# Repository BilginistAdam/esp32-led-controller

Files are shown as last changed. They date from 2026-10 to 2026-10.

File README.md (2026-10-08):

<p align="center">
  <picture>
    <source media="(prefers-color-scheme: dark)" srcset="docs/logo/banner-dark.svg">
    LED Controller · Bilginier
  </picture>
</p>

# LED Controller — ESP32-C3 LED Şerit Kontrolcüsü

12–24 V LED şeritleri WiFi üzerinden açıp kapatan ve PWM ile dimleyen küçük bir kontrol kartı. Proje KiCad donanım dosyalarını, iki firmware seçeneğini (ESPHome / PlatformIO) ve 3D yazıcıyla basılabilen bir kutuyu içerir.

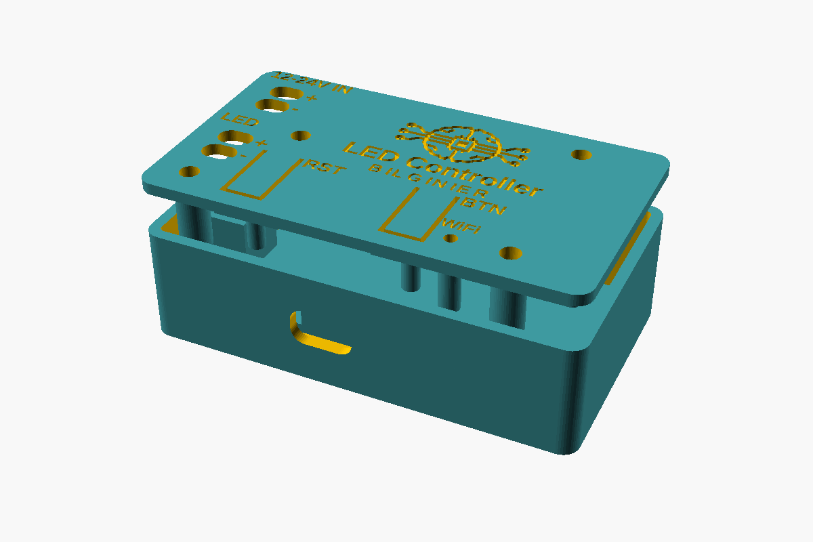
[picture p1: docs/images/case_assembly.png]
Kutu


| PCB üst | Şematik |
|---|---|
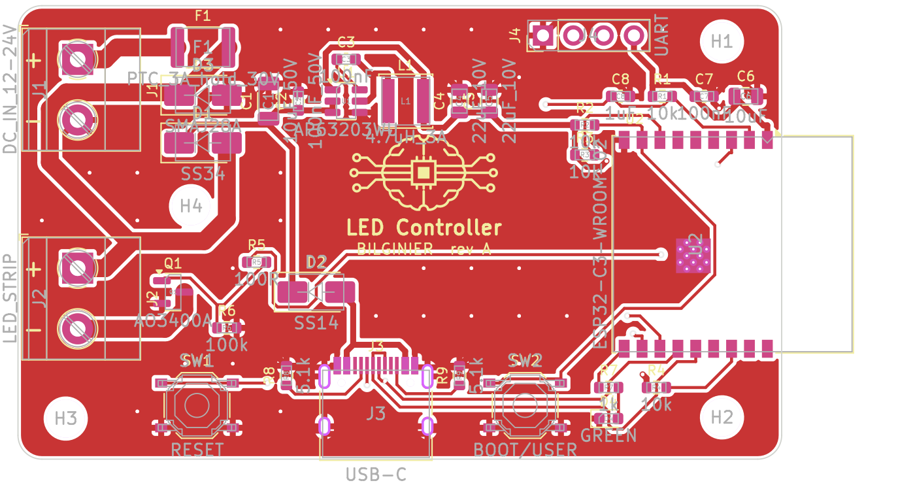
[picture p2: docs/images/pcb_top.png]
PCB
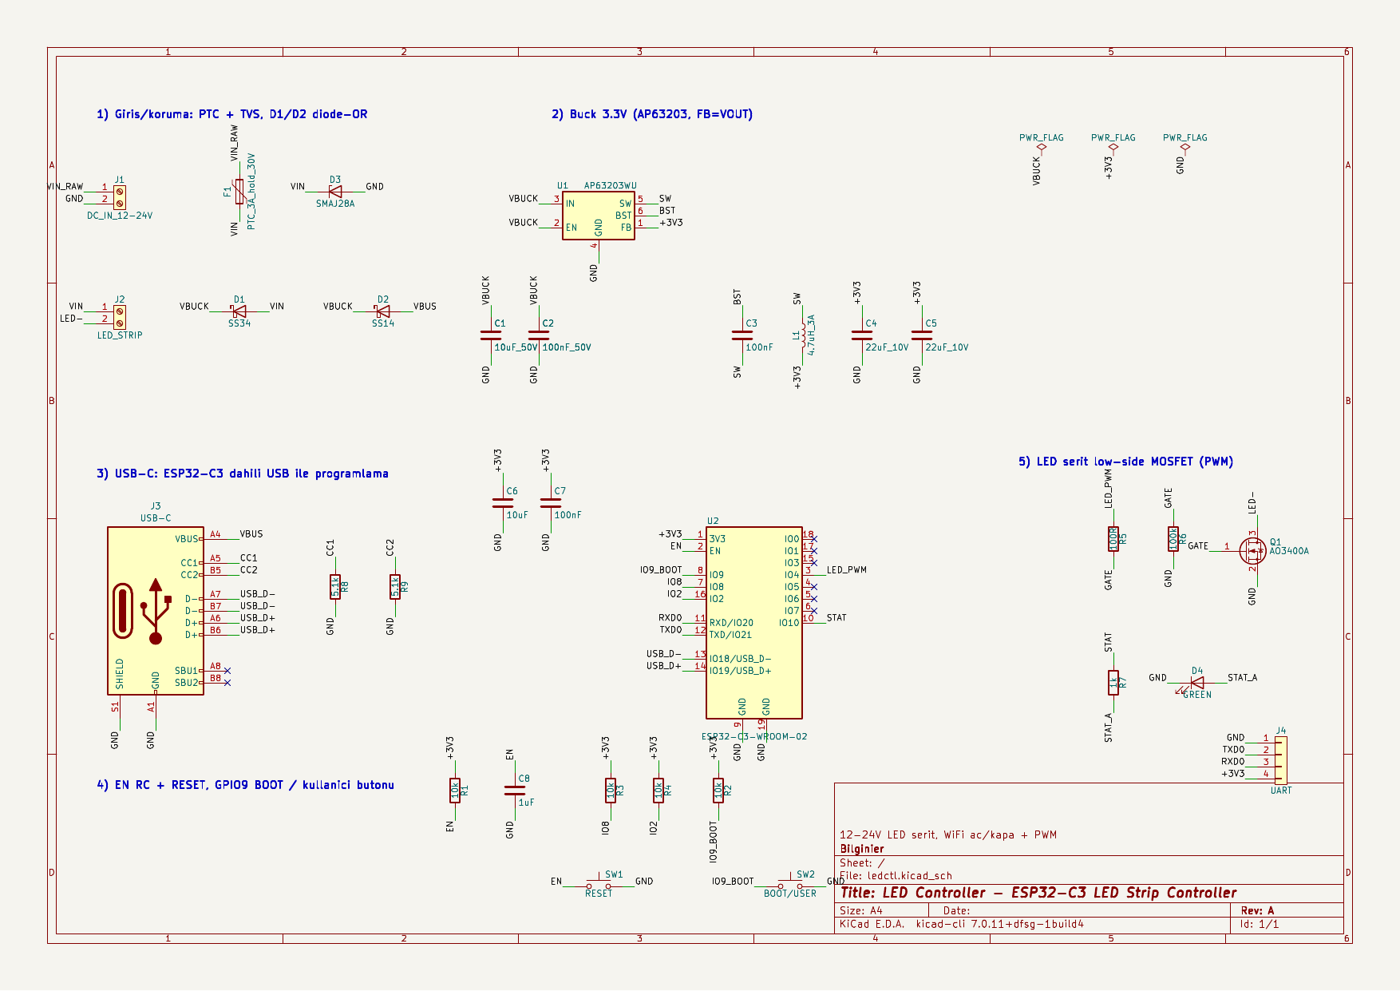
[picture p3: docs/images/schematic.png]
Şematik
|  |  |

## Özellikler

- **Kontrol:** ESP32-C3-WROOM-02 (WiFi + BLE). Programlama dahili USB üzerinden USB-C ile yapılıyor, ayrı bir USB-UART çipi yok.
- **Giriş:** 12–24 V DC. PTC sigorta ve TVS ile korunuyor. AP63203 buck regülatör 3.3 V üretiyor.
- **Besleme:** D1/D2 diyotlarıyla kart adaptörden **ya da** sadece USB'den beslenebiliyor, yani programlarken adaptör gerekmiyor.
- **LED sürme:** LED şeridini low-side AO3400A MOSFET anahtarlıyor. 20 kHz PWM kullanılıyor, böylece duyulabilir vızıltı olmuyor. Gate'teki pull-down sayesinde LED boot sırasında kapalı kalıyor.
- **Arayüz:** RESET butonu, BOOT/kullanıcı butonu ve durum LED'i var.
- **Kart:** 64 × 38 mm, 2 katman, 4 × M3 montaj deliği.

## Klasör yapısı

```
hardware/          KiCad projesi (şematik, PCB, proje sembol kütüphanesi)
  BOM.md / BOM.csv malzeme listesi (okunabilir tablo / üretici formatı)
  ledctl-gerbers.zip   üreticiye (JLCPCB/PCBWay vb.) doğrudan yüklenebilir
  fabrication/     Gerber, drill, pick-and-place (pos) dosyaları
  scripts/         şematik/PCB'yi üreten Python betikleri (design.py = tek kaynak)
firmware/
  esphome/         Home Assistant için ESPHome konfigürasyonu
  platformio/      bağımsız Arduino firmware'i (web arayüzü + REST API)
    prebuilt/      derlenmiş factory imajı (0x0 adresine yazılır)
enclosure/         OpenSCAD kaynak + basılmaya hazır STL'ler
docs/              şematik PDF, PCB montaj PDF'i, görseller
  logo/            Bilginier logosu (SVG) + üretici betik (PCB, kutu ve banner aynı kaynaktan)
```

## Malzeme listesi (BOM)

Ayrıntılı liste için [`hardware/BOM.md`](hardware/BOM.md), makineli montaj için [`hardware/BOM.csv`](hardware/BOM.csv) dosyasına bak.

| Adet | Ref | Parça | LCSC |
|---:|---|---|---|
| 1 | U2 | ESP32-C3-WROOM-02-N4 | C2934560 |
| 1 | U1 | AP63203WU-7 (3.3 V buck) | C780769 |
| 1 | Q1 | AO3400A | C20917 |
| 1 | L1 | FNR4030S4R7MT, 4.7 µH | C167874 |
| 1 / 1 / 1 | D1 / D2 / D3 | SS34 / SS14 / SMAJ28A | C8678 / C2480 / C353458 |
| 1 | D4 | Yeşil LED 0603 | C72043 |
| 1 | F1 | PTC 1812 (bkz. BOM.md notu) | — |
| 1 | C1 | 10 µF 50 V 1206 | C13585 |
| 3 | C2, C3, C7 | 100 nF 50 V 0603 | C14663 |
| 2 | C4, C5 | 22 µF 25 V 0805 | C45783 |
| 1 / 1 | C6 / C8 | 10 µF 0805 / 1 µF 0603 | C15850 / C15849 |
| 4 | R1–R4 | 10 kΩ 0603 | C25804 |
| 1 / 1 / 1 | R5 / R6 / R7 | 100 Ω / 100 kΩ / 1 kΩ 0603 | C22775 / C25803 / C21190 |
| 2 | R8, R9 | 5.1 kΩ 0603 | C23186 |
| 2 | J1, J2 | Phoenix 1715721, 2P 5.08 mm | C480516 |
| 1 | J3 | USB-C HRO TYPE-C-31-M-12 | C165948 |
| 1 | J4 | 1×4 pin header (opsiyonel) | C2337 |
| 2 | SW1, SW2 | TS-1187A-B-A-B | C318884 |
| 4 | — | M3 × 20 vida (kutu) | — |

JLCPCB montaj için hazır dosyalar: `hardware/fabrication/ledctl-bom-jlcpcb.csv` ve `ledctl-cpl-jlcpcb.csv`.

## Pin haritası

| GPIO | İşlev |
|---|---|
| IO4 | LED PWM → R5 → Q1 gate |
| IO9 | BOOT / kullanıcı butonu (aktif düşük) |
| IO10 | Durum LED'i (aktif yüksek) |
| IO18 / IO19 | USB D− / D+ (USB-C) |
| IO20 / IO21 | UART RX / TX (J4, opsiyonel) |

## Firmware

### Seçenek A: ESPHome (Home Assistant)

```bash
cd firmware/esphome
cp secrets.yaml.example secrets.yaml   # WiFi bilgilerini gir
esphome run ledctl.yaml                # ilk yükleme USB-C üzerinden
```

Bu seçenek Home Assistant'a "LED Serit" adlı, dimlenebilir bir ışık olarak eklenir. Butona basınca LED açılıp kapanır, durum LED'i WiFi bağlantısını gösterir.

### Seçenek B: PlatformIO (bağımsız)

```bash
cd firmware/platformio
pio run -t upload        # USB-C
pio device monitor
```

1. **WiFi kurulumu:** İlk açılışta kart `LedCtrl-Setup` adında bir WiFi ağı açar. Bu ağa bağlanıp açılan sayfadan kendi WiFi bilgilerini gir.
2. **Web arayüzü:** Kurulumdan sonra `http://led-ctrl.local` adresinden aç/kapat ve parlaklık ayarı yapılabilir.
3. **REST API:**
   ```bash
   curl http://led-ctrl.local/api/state
   curl -X POST http://led-ctrl.local/api/state -d '{"on":true,"brightness":60}'
   curl -X POST http://led-ctrl.local/api/toggle
   ```
4. **Buton:**
   - Kısa basış: aç/kapat
   - Basılı tutma: parlaklığı 100 → 75 → 50 → 25 → 10 sırasıyla değiştirir
   - 8 saniye basılı tutma: WiFi ayarlarını siler
5. **Durum LED'i:**
   - Sürekli yanık: bağlı
   - Yavaş yanıp sönme: bağlanıyor
   - Hızlı yanıp sönme: kurulum modunda
6. **Diğer:** Son durum NVS'e kaydedilir, elektrik kesilip gelince geri yüklenir. Ayrıca OTA güncelleme (ArduinoOTA) destekleniyor.

Hazır imajı yazmak için:

```bash
esptool.py --chip esp32c3 write_flash 0x0 firmware/platformio/prebuilt/ledctl-factory.bin
```

> **Yükleme başlamazsa:** **BOOT**'a basılı tutarken **RESET**'e bas ve bırak. Kart indirme moduna geçer. Normalde USB üzerinden otomatik reset yeterli olur.

## Kutu (3D baskı)

| Parça | Dosya | Baskı yönü |
|---|---|---|
| Gövde | `enclosure/ledctl_case_base.stl` | taban aşağıda |
| Kapak | `enclosure/ledctl_case_lid.stl` | yüzü aşağıda (dosya zaten bu yönde) |

- **Önerilen baskı ayarları:** PETG veya PLA, 0.2 mm katman, %20–30 doluluk. Destek gerekmiyor.
- **Montaj:** 4 adet **M3 × 20** vida kapaktan girer, PCB'yi sıkıştırır ve gövdedeki direklere tutunur. Vidalar plastiğe kendi yolunu açabilir; isteğe bağlı olarak `pilot_d = 4.0` ile heat-set insert de kullanılabilir.
- **Duvara montaj:** Tabanda 20 mm aralıklı iki anahtar deliği var, en fazla 8 mm başlı vida uygun. USB-C aşağı bakacak şekilde asılır.
- **Bantla montaj:** Taban tamamen düz olduğu için çift taraflı bantla da yapıştırılabilir.
- **Butonlar:** RESET ve BOOT butonları kapaktaki esnek dillerle basılır. Durum LED'inin ışığı kapaktaki tüpten görünür.
- **Terminaller:** Vidalarına kapaktaki deliklerden tornavidayla erişilir.
- **Ölçüler:** `enclosure/ledctl_case.scad` içindeki parametrelerden (tolerans, duvar kalınlığı, yükseklik) değiştirilebilir.

```bash
openscad -D 'part="base"' -o enclosure/ledctl_case_base.stl enclosure/ledctl_case.scad
openscad -D 'part="lid"'  -o enclosure/ledctl_case_lid.stl  enclosure/ledctl_case.scad
```

## Üretim

1. `hardware/ledctl-gerbers.zip` dosyasını PCB üreticisine yükle. Ayarlar: 2 katman, 1.6 mm, 1 oz bakır.
2. Montaj için `hardware/BOM.csv` (okunabilir hali: `hardware/BOM.md`) ve `hardware/fabrication/ledctl-pos.csv` dosyalarını kullan.
3. ESP modülünün anteni kartın sağ kenarından yaklaşık 6 mm dışarı taşar. Bu bilinçli bir tercih: antenin altında bakır olmaması gerekiyor. Kutu bu taşmaya göre tasarlandı.

## Tasarım notları ve sınırlar

- **Akım:** AO3400A ile kart yaklaşık **3 A** LED akımı için uygun. 24 V'ta bu yaklaşık 70 W, 12 V'ta yaklaşık 36 W eder. Daha yüksek akım için daha güçlü bir MOSFET kullanılmalı ve LED izleri genişletilmeli.
- **Gerilim:** AP63203 en fazla 32 V girişe dayanır. 24 V adaptörlerde sorun yok. TVS (SMAJ28A) kısa süreli darbelere karşı korur, ama sürekli aşırı gerilimden korumaz.
- **F1 sigorta:** 3 A / 24 V için 1812 kılıfta uygun bir PTC yok. Seçenekler [`hardware/BOM.md`](hardware/BOM.md) notunda anlatılıyor.
- **Routing:** İzler Freerouting ile otomatik çizildi. DRC'de elektriksel hata yok, sadece kozmetik silkscreen uyarıları var. Sipariş vermeden önce KiCad 8/9'da ERC ve DRC'yi kendin de çalıştır.
- **Yeniden üretme:** `hardware/scripts/` içindeki betikler şematik ve PCB'yi `design.py` ve `placement.py` dosyalarından üretir. Logo ve isim en son `add_branding.py` ile silkscreen'e eklenir. Bunun için KiCad 7+ Python (`pcbnew`) ve otomatik routing için Freerouting gerekir (`FREEROUTING_JAR` ortam değişkeni).

## Lisans

[MIT](LICENSE). Donanım dosyaları, firmware ve kutu dahil projenin tamamı bu lisansla yayınlanır.

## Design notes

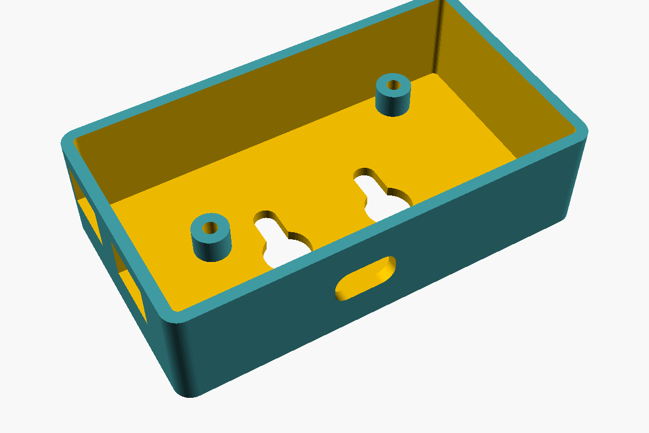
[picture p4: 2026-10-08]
docs/images/case_base.png

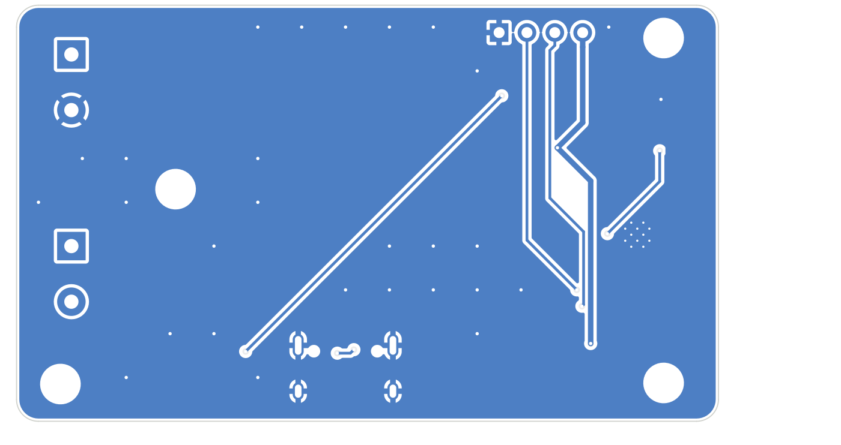
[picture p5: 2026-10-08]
docs/images/pcb_bottom.png

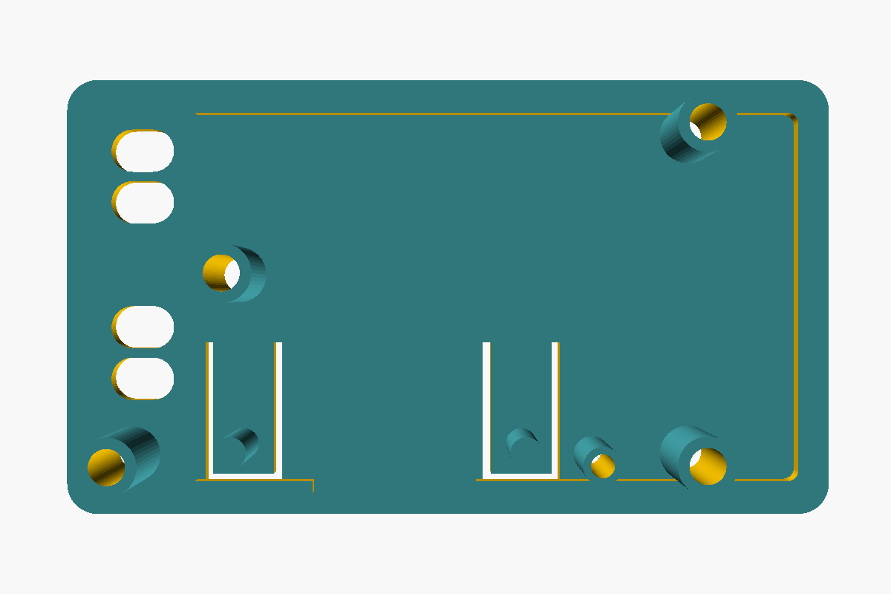
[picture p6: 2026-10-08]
docs/images/case_lid.png

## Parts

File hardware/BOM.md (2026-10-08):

<p align="center">Bilginier</p>

# Malzeme Listesi (BOM) — LED Controller rev A

Bir kart için 23 kalem ve toplam 32 parça gerekiyor. LCSC numaralarının hepsi Ekim 2026'da lcsc.com'da doğrulandı. Stok durumu sürekli değiştiği için sipariş öncesi yeniden kontrol et.

**Hangi dosyayı kullanmalısın:**

- **Elle sipariş:** `BOM.csv` (üretici parça numarası ve LCSC numarası birlikte).
- **JLCPCB montaj:** `fabrication/ledctl-bom-jlcpcb.csv` ve `fabrication/ledctl-cpl-jlcpcb.csv`. J4 bu listelerde yok, istersen elle lehimlenir.

## Aktif parçalar

| Adet | Ref | Değer | Açıklama | Kılıf | Üretici parça no | LCSC |
|---:|---|---|---|---|---|---|
| 1 | U2 | ESP32-C3-WROOM-02-N4 | WiFi/BLE modül, 4 MB flash, PCB anten | Modül | Espressif ESP32-C3-WROOM-02-N4 | [C2934560](https://www.lcsc.com/product-detail/C2934560.html) |
| 1 | U1 | AP63203WU | Senkron buck, 3.8–32 V → 3.3 V / 2 A | TSOT-23-6 | Diodes AP63203WU-7 | [C780769](https://www.lcsc.com/product-detail/C780769.html) |
| 1 | Q1 | AO3400A | N-MOSFET 30 V / 5.7 A, lojik seviye | SOT-23 | AOS AO3400A | [C20917](https://www.lcsc.com/product-detail/C20917.html) |
| 1 | D1 | SS34 | Schottky 40 V / 3 A (adaptör → buck) | SMA | MDD SS34 | [C8678](https://www.lcsc.com/product-detail/C8678.html) |
| 1 | D2 | SS14 | Schottky 40 V / 1 A (USB → buck) | SMA | MDD SS14 | [C2480](https://www.lcsc.com/product-detail/C2480.html) |
| 1 | D3 | SMAJ28A | TVS 28 V, tek yönlü | SMA | Jingdao SMAJ28A | [C353458](https://www.lcsc.com/product-detail/C353458.html) |
| 1 | D4 | Yeşil LED | Durum LED'i | 0603 | Everlight 19-217/GHC-YR1S2/3T | [C72043](https://www.lcsc.com/product-detail/C72043.html) ¹ |

## Pasifler

| Adet | Ref | Değer | Açıklama | Kılıf | Üretici parça no | LCSC |
|---:|---|---|---|---|---|---|
| 1 | L1 | 4.7 µH | Güç bobini, Isat 3.2 A, ekranlı | 4×4 mm | Changjiang FNR4030S4R7MT | [C167874](https://www.lcsc.com/product-detail/C167874.html) |
| 1 | F1 | PTC | Resetlenebilir sigorta | 1812 | **belirlenecek** ² | — |
| 1 | C1 | 10 µF 50 V | Buck giriş, X5R | 1206 | Samsung CL31A106KBHNNNE | [C13585](https://www.lcsc.com/product-detail/C13585.html) |
| 3 | C2, C3, C7 | 100 nF 50 V | Buck HF (C2), bootstrap (C3), modül (C7), X7R | 0603 | Yageo CC0603KRX7R9BB104 | [C14663](https://www.lcsc.com/product-detail/C14663.html) |
| 2 | C4, C5 | 22 µF 25 V | Buck çıkış, X5R | 0805 | Samsung CL21A226MAQNNNE | [C45783](https://www.lcsc.com/product-detail/C45783.html) |
| 1 | C6 | 10 µF 25 V | Modül besleme, X5R | 0805 | Samsung CL21A106KAYNNNE | [C15850](https://www.lcsc.com/product-detail/C15850.html) |
| 1 | C8 | 1 µF 50 V | EN RC gecikmesi, X5R | 0603 | Samsung CL10A105KB8NNNC | [C15849](https://www.lcsc.com/product-detail/C15849.html) ¹ |
| 4 | R1–R4 | 10 kΩ %1 | EN ve strapping pull-up'ları | 0603 | UNI-ROYAL 0603WAF1002T5E | [C25804](https://www.lcsc.com/product-detail/C25804.html) ¹ |
| 1 | R5 | 100 Ω %1 | Gate seri direnci | 0603 | UNI-ROYAL 0603WAF1000T5E | [C22775](https://www.lcsc.com/product-detail/C22775.html) |
| 1 | R6 | 100 kΩ %1 | Gate pull-down | 0603 | UNI-ROYAL 0603WAF1003T5E | [C25803](https://www.lcsc.com/product-detail/C25803.html) |
| 1 | R7 | 1 kΩ %1 | Durum LED'i direnci | 0603 | UNI-ROYAL 0603WAF1001T5E | [C21190](https://www.lcsc.com/product-detail/C21190.html) |
| 2 | R8, R9 | 5.1 kΩ %1 | USB-C CC pull-down | 0603 | UNI-ROYAL 0603WAF5101T5E | [C23186](https://www.lcsc.com/product-detail/C23186.html) |

## Elektromekanik

| Adet | Ref | Değer | Açıklama | Üretici parça no | LCSC |
|---:|---|---|---|---|---|
| 2 | J1, J2 | 2P, 5.08 mm | Vidalı klemens (J1 = 12–24 V giriş, J2 = LED şerit) | Phoenix Contact 1715721 | [C480516](https://www.lcsc.com/product-detail/C480516.html) |
| 1 | J3 | USB-C 16P | USB 2.0 Type-C dişi | HRO TYPE-C-31-M-12 | [C165948](https://www.lcsc.com/product-detail/C165948.html) |
| 1 | J4 | 1×4, 2.54 mm | UART header (opsiyonel, 1×40 şeritten kesilir) | BOOMELE 2.54-1*40P | [C2337](https://www.lcsc.com/product-detail/C2337.html) |
| 2 | SW1, SW2 | 5.1×5.1×1.5 mm | Tact switch (RESET / BOOT) | XKB TS-1187A-B-A-B | [C318884](https://www.lcsc.com/product-detail/C318884.html) |

## Kutu ve montaj

| Adet | Parça | Not |
|---:|---|---|
| 1 | Gövde (`enclosure/ledctl_case_base.stl`) | PETG veya PLA |
| 1 | Kapak (`enclosure/ledctl_case_lid.stl`) | Yüzü aşağı basılır, logo kazınmış |
| 4 | M3 × 20 vida | Plastiğe yol açan tip, ya da M3 heat-set insert ile makine vidası |
| 2 | Duvar vidası + dübel | Başı en fazla 8 mm, gövdesi en fazla 4 mm (anahtar deliği için) |
| — | Çift taraflı bant | Opsiyonel, düz taban için |

## PCB

| Özellik | Değer |
|---|---|
| Ölçü | 64 × 38 mm |
| Katman | 2 |
| Kalınlık | 1.6 mm |
| Bakır | 1 oz |
| Min. iz / boşluk | 0.2 / 0.2 mm |
| Min. delik | 0.3 mm (via) |
| Üretim dosyası | `ledctl-gerbers.zip` |

## Notlar

¹ **Stok:** Bu parçalar kontrol sırasında LCSC mağazasında stokta yoktu ya da azdı. Hepsi yaygın parçalar, JLCPCB montaj stoğu ayrı tutulur. Yoksa aynı değer ve kılıfta başka bir parça kullanılabilir.

² **F1 (PTC sigorta):** 1812 kılıfta 24 V'a dayanıp 3 A taşıyan bir PTC bulunmuyor. 24 V sınıfı 1812 PTC'ler en fazla 1.5 A civarında kalıyor, 3 A olanlar ise 8 V'a kadar dayanıyor (örneğin C21004). Bu yüzden kalem şimdilik boş bırakıldı. Seçenekler:

- **Daha düşük akım:** 1.5 A / 24 V'luk bir 1812 PTC kullan. Şerit akımı da bununla sınırlı kalır.
- **Daha büyük kılıf:** 2920 kılıfta daha yüksek akımlı bir PTC kullan. Bunun için PCB'de footprint değişikliği gerekir.
- **Tek kullanımlık sigorta:** SMD bir eriyen sigorta kullan. Bu da PCB değişikliği gerektirir.

Prototip için F1 yerine 0 Ω köprü ya da kısa bir tel de konabilir, ama bu durumda aşırı akım koruması kalmaz.

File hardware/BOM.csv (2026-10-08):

Qty | References | Value | Description | Package / Footprint | Manufacturer part number | LCSC
1 | U2 | ESP32-C3-WROOM-02-N4 | Wi-Fi/BLE module, 4 MB flash, PCB antenna | ESP32-C3-WROOM-02 | Espressif ESP32-C3-WROOM-02-N4 | C2934560
1 | U1 | AP63203WU | Synchronous buck 3.8-32 V in, 3.3 V / 2 A out, 1.1 MHz | TSOT-23-6 | Diodes Inc. AP63203WU-7 | C780769
1 | Q1 | AO3400A | N-MOSFET 30 V / 5.7 A, logic level (LED strip switch) | SOT-23 | Alpha & Omega AO3400A | C20917
1 | L1 | 4.7uH | Power inductor 4.7 uH, Isat 3.2 A, shielded | 4.0 x 4.0 mm (FNR4030S) | Changjiang FNR4030S4R7MT | C167874
1 | D1 | SS34 | Schottky 40 V / 3 A (adapter -> buck, diode-OR) | SMA | MDD SS34 | C8678
1 | D2 | SS14 | Schottky 40 V / 1 A (USB VBUS -> buck, diode-OR) | SMA | MDD SS14 | C2480
1 | D3 | SMAJ28A | TVS 28 V standoff, unidirectional | SMA | Jingdao SMAJ28A | C353458
1 | D4 | GREEN | Status LED, green | 0603 | Everlight 19-217/GHC-YR1S2/3T | C72043
1 | F1 | PTC | Resettable fuse - see BOM.md note: no 1812 part covers 3 A at 24 V | 1812 | TBD
1 | C1 | 10uF 50V | Buck input bulk, X5R | 1206 | Samsung CL31A106KBHNNNE | C13585
3 | C2 C3 C7 | 100nF 50V | Buck input HF (C2), bootstrap (C3), module decoupling (C7), X7R | 0603 | Yageo CC0603KRX7R9BB104 | C14663
2 | C4 C5 | 22uF 25V | Buck output, X5R | 0805 | Samsung CL21A226MAQNNNE | C45783
1 | C6 | 10uF 25V | Module bulk decoupling, X5R | 0805 | Samsung CL21A106KAYNNNE | C15850
1 | C8 | 1uF 50V | EN RC delay, X5R | 0603 | Samsung CL10A105KB8NNNC | C15849
4 | R1 R2 R3 R4 | 10k 1% | EN pull-up, strapping pull-ups (IO9 / IO8 / IO2) | 0603 | UNI-ROYAL 0603WAF1002T5E | C25804
1 | R5 | 100R 1% | MOSFET gate series resistor | 0603 | UNI-ROYAL 0603WAF1000T5E | C22775
1 | R6 | 100k 1% | MOSFET gate pull-down (LED off during boot) | 0603 | UNI-ROYAL 0603WAF1003T5E | C25803
1 | R7 | 1k 1% | Status LED series resistor | 0603 | UNI-ROYAL 0603WAF1001T5E | C21190
2 | R8 R9 | 5.1k 1% | USB-C CC1/CC2 pull-downs (sink role) | 0603 | UNI-ROYAL 0603WAF5101T5E | C23186
2 | SW1 SW2 | TS-1187A | Tactile switch 5.1 x 5.1 x 1.5 mm (RESET / BOOT-user) | SMD 4-pad | XKB TS-1187A-B-A-B | C318884
1 | J3 | USB-C 16P | USB 2.0 Type-C receptacle, SMD + THT shell | HRO TYPE-C-31-M-12 | Korean Hroparts TYPE-C-31-M-12 | C165948
2 | J1 J2 | 2-pos 5.08 mm | Screw terminal block (J1 = 12-24 V in, J2 = LED strip) | Phoenix MKDS 1.5/2-5.08 | Phoenix Contact 1715721 | C480516
1 | J4 | 1x4 2.54 mm | UART/debug header (optional; cut from 1x40 strip) | PinHeader_1x04_P2.54mm | BOOMELE 2.54-1*40P | C2337
 |  |  | Enclosure hardware
4 |  | M3 x 20 | Pan head self-tapping (or machine screw with M3 heat-set inserts)

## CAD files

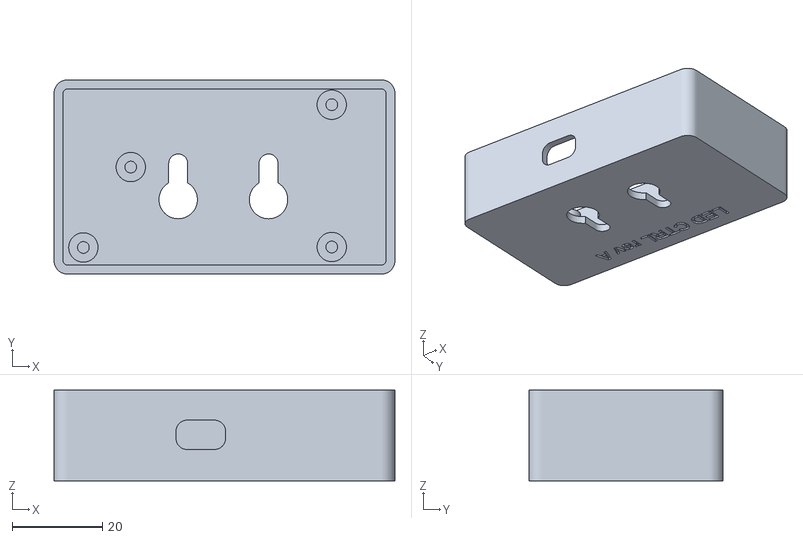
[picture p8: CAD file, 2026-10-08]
enclosure/ledctl_case_base.stl
75.5 x 43.0 x 20.1

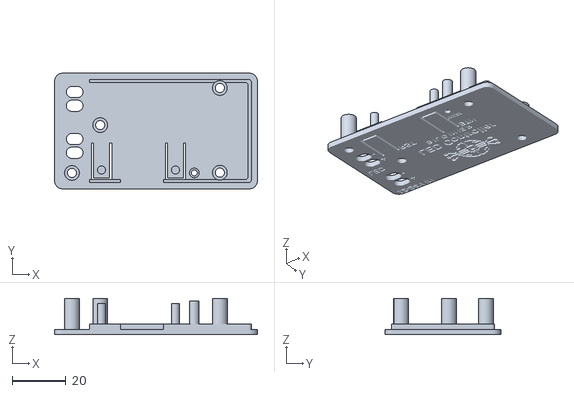
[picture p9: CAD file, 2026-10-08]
enclosure/ledctl_case_lid.stl
75.5 x 43.0 x 13.5

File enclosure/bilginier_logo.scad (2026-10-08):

// Generated by docs/logo/logo.py (stroke x1.8 for FDM engraving). Do not edit by hand.
// bilginier_logo(height): centered at origin, Y up.
module bilginier_logo(height = 12) {
  scale(height / 114.117)
  polygon(points = [[-91.13,27.17],[-92.27,28.31],[-93.62,29.21],[-95.11,29.83],[-96.69,30.14],[-98.31,30.14],[-99.89,29.83],[-101.38,29.21],[-102.73,28.31],[-103.87,27.17],[-104.77,25.83],[-105.39,24.34],[-105.70,22.75],[-105.70,21.14],[-105.39,19.55],[-104.77,18.06],[-103.87,16.72],[-102.08,15.09],[-100.65,14.33],[-98.31,13.74],[-96.69,13.74],[-94.35,14.33],[-92.92,15.09],[-91.13,16.72],[-89.93,18.70],[-83.34,18.70],[-72.29,7.65],[-71.53,7.09],[-70.00,6.70],[-62.24,6.70],[-62.85,5.32],[-63.37,3.18],[-93.93,3.18],[-94.65,4.52],[-95.67,5.77],[-97.62,7.21],[-99.11,7.83],[-100.69,8.14],[-103.11,8.02],[-104.65,7.56],[-106.73,6.31],[-108.35,4.52],[-109.39,2.34],[-109.74,-0.06],[-109.58,-1.66],[-109.11,-3.21],[-107.87,-5.28],[-106.73,-6.43],[-105.38,-7.32],[-103.89,-7.94],[-101.50,-8.30],[-99.11,-7.94],[-96.92,-6.91],[-95.13,-5.28],[-93.93,-3.30],[-63.32,-3.30],[-62.25,-6.82],[-70.00,-6.82],[-71.53,-7.20],[-72.29,-7.77],[-83.34,-18.82],[-89.93,-18.82],[-91.13,-16.83],[-92.27,-15.69],[-93.62,-14.79],[-95.89,-13.98],[-98.31,-13.86],[-99.89,-14.17],[-101.38,-14.79],[-102.73,-15.69],[-103.87,-16.83],[-104.77,-18.17],[-105.58,-20.45],[-105.70,-22.86],[-105.39,-24.45],[-104.35,-26.63],[-103.33,-27.88],[-102.08,-28.91],[-100.65,-29.67],[-98.31,-30.26],[-96.69,-30.26],[-94.35,-29.67],[-92.92,-28.91],[-91.13,-27.28],[-89.93,-25.30],[-82.00,-25.30],[-81.06,-25.16],[-79.71,-24.35],[-68.66,-13.30],[-60.82,-13.30],[-60.87,-15.17],[-60.40,-18.10],[-59.06,-21.70],[-55.97,-25.95],[-52.52,-28.34],[-52.19,-30.70],[-51.02,-33.82],[-49.25,-36.64],[-46.28,-39.63],[-41.56,-42.20],[-38.53,-42.80],[-37.82,-44.20],[-35.86,-46.83],[-33.69,-48.84],[-30.90,-50.58],[-27.83,-51.73],[-24.91,-52.23],[-21.63,-52.19],[-20.15,-51.90],[-18.19,-53.83],[-13.24,-56.37],[-9.93,-57.06],[-6.18,-57.05],[-5.27,-56.83],[-4.45,-56.35],[-3.65,-55.39],[-2.97,-52.85],[-2.26,-51.80],[-1.22,-51.10],[0.00,-50.86],[1.22,-51.10],[2.26,-51.80],[2.97,-52.85],[3.65,-55.39],[4.71,-56.54],[6.18,-57.05],[10.30,-57.04],[13.54,-56.29],[16.53,-54.93],[19.22,-53.00],[20.22,-51.92],[21.63,-52.19],[24.91,-52.23],[27.83,-51.73],[31.18,-50.42],[33.69,-48.84],[35.86,-46.83],[37.82,-44.20],[38.50,-42.86],[40.30,-42.59],[43.41,-41.42],[46.19,-39.69],[48.75,-37.26],[51.48,-32.78],[52.42,-29.68],[52.57,-28.31],[56.01,-25.91],[58.08,-23.38],[59.50,-20.77],[60.58,-17.35],[60.89,-14.40],[60.82,-13.30],[68.66,-13.30],[80.20,-24.75],[81.68,-25.28],[89.93,-25.30],[91.13,-27.28],[92.27,-28.43],[94.35,-29.67],[95.89,-30.14],[97.50,-30.30],[99.11,-30.14],[100.65,-29.67],[102.08,-28.91],[103.87,-27.28],[104.77,-25.94],[105.39,-24.45],[105.70,-22.86],[105.70,-21.25],[105.39,-19.66],[104.77,-18.17],[103.33,-16.23],[102.08,-15.21],[100.65,-14.44],[98.31,-13.86],[96.69,-13.86],[95.11,-14.17],[93.62,-14.79],[92.27,-15.69],[91.13,-16.83],[89.93,-18.82],[83.34,-18.82],[72.29,-7.77],[71.53,-7.20],[70.00,-6.82],[62.24,-6.82],[62.87,-5.39],[63.31,-3.30],[93.93,-3.30],[95.13,-5.28],[96.92,-6.91],[99.11,-7.94],[100.69,-8.26],[102.31,-8.26],[103.89,-7.94],[105.38,-7.32],[106.73,-6.43],[108.35,-4.63],[109.39,-2.45],[109.74,-0.06],[109.58,1.55],[108.77,3.83],[107.87,5.17],[106.08,6.79],[103.89,7.83],[102.31,8.14],[100.69,8.14],[98.35,7.56],[96.92,6.79],[95.67,5.77],[94.65,4.52],[93.93,3.18],[63.32,3.18],[62.25,6.70],[70.00,6.70],[71.53,7.09],[72.29,7.65],[83.34,18.70],[89.93,18.70],[91.13,16.72],[92.27,15.57],[94.35,14.33],[95.89,13.86],[98.31,13.74],[99.89,14.06],[101.38,14.68],[102.73,15.57],[104.35,17.37],[105.11,18.79],[105.70,21.14],[105.70,22.75],[105.11,25.10],[103.87,27.17],[102.73,28.31],[101.38,29.21],[99.89,29.83],[97.50,30.18],[95.89,30.02],[94.35,29.56],[92.27,28.31],[91.13,27.17],[89.93,25.18],[82.00,25.18],[80.76,24.94],[79.71,24.23],[68.66,13.18],[60.82,13.18],[60.87,15.06],[60.40,17.99],[59.06,21.59],[55.97,25.83],[52.52,28.23],[52.19,30.58],[51.02,33.70],[49.25,36.53],[46.28,39.51],[41.56,42.08],[38.53,42.69],[37.76,44.17],[35.37,47.25],[32.43,49.58],[29.27,51.14],[28.37,51.43],[23.67,52.19],[20.32,51.70],[19.08,53.01],[15.93,55.12],[12.44,56.50],[8.27,57.06],[5.97,56.91],[5.09,56.63],[4.32,56.12],[3.72,55.40],[2.80,52.47],[1.70,51.25],[0.62,50.81],[-0.71,50.81],[-1.52,51.10],[-2.21,51.61],[-2.97,52.74],[-3.40,54.70],[-4.03,55.82],[-5.34,56.74],[-6.60,56.95],[-11.22,56.77],[-15.17,55.50],[-19.08,53.01],[-20.22,51.81],[-21.63,52.07],[-24.91,52.12],[-27.83,51.62],[-31.18,50.31],[-33.69,48.73],[-36.09,46.49],[-38.00,43.82],[-38.56,42.62],[-42.13,41.86],[-45.30,40.22],[-47.84,38.13],[-49.73,35.85],[-51.47,32.70],[-52.42,29.57],[-52.57,28.19],[-56.01,25.80],[-58.08,23.27],[-59.50,20.66],[-60.58,17.23],[-60.89,14.28],[-60.82,13.18],[-68.66,13.18],[-80.20,24.64],[-81.68,25.17],[-89.93,25.18],[-2.99,25.70],[-2.55,24.94],[-2.99,24.18],[-3.22,23.26],[-3.24,20.18],[-6.76,20.18],[-6.78,23.26],[-7.14,24.47],[-8.20,25.64],[-9.06,26.04],[-10.00,26.18],[-10.94,26.04],[-11.80,25.64],[-12.86,24.47],[-13.22,23.26],[-13.24,20.18],[-20.24,20.18],[-20.24,13.18],[-54.23,13.18],[-54.40,14.10],[-54.21,15.96],[-53.63,17.89],[-52.68,19.66],[-51.51,21.09],[-48.05,23.43],[-46.94,22.84],[-46.00,22.70],[-36.00,22.70],[-35.01,22.86],[-34.40,23.12],[-33.41,24.00],[-27.41,32.00],[-26.96,32.84],[-26.76,34.08],[-27.21,35.59],[-28.06,36.54],[-29.51,37.15],[-30.77,37.09],[-31.65,36.73],[-32.39,36.13],[-37.62,29.18],[-45.78,29.18],[-45.47,30.22],[-44.52,31.99],[-43.25,33.54],[-41.70,34.82],[-40.05,35.69],[-35.33,36.69],[-34.26,37.26],[-33.47,38.18],[-32.37,40.57],[-31.20,42.20],[-29.74,43.58],[-28.03,44.64],[-26.15,45.35],[-24.17,45.67],[-22.17,45.61],[-19.23,44.98],[-17.99,45.17],[-16.92,45.82],[-14.93,48.00],[-12.69,49.50],[-10.20,50.34],[-9.06,50.38],[-8.70,49.66],[-6.81,46.98],[-4.73,45.43],[-3.24,44.83],[-3.24,26.94],[2.55,24.94],[3.10,26.00],[3.24,26.94],[3.24,44.88],[5.17,45.70],[5.76,46.11],[8.33,48.94],[8.97,50.45],[10.86,50.20],[12.64,49.53],[14.93,48.00],[16.93,45.81],[18.04,45.15],[19.32,44.98],[23.50,45.67],[26.84,45.12],[29.23,43.93],[30.70,42.73],[32.39,40.52],[33.48,38.17],[34.30,37.23],[35.42,36.67],[39.27,35.98],[42.27,34.38],[44.16,32.49],[45.19,30.83],[45.81,29.18],[37.62,29.18],[32.39,36.13],[31.65,36.73],[30.77,37.09],[29.20,37.08],[27.81,36.33],[26.94,35.02],[26.76,33.77],[26.96,32.84],[27.41,32.00],[33.41,24.00],[34.40,23.12],[35.01,22.86],[36.00,22.70],[46.00,22.70],[46.94,22.84],[48.05,23.43],[51.42,21.15],[53.39,18.40],[54.06,16.62],[54.39,14.64],[54.34,13.18],[20.24,13.18],[20.24,20.18],[13.24,20.18],[13.22,23.26],[12.86,24.47],[12.29,25.23],[11.53,25.80],[10.00,26.18],[8.47,25.80],[7.71,25.23],[7.14,24.47],[6.78,23.26],[6.76,20.18],[3.24,20.18],[3.22,23.26],[2.99,24.18],[-20.24,6.70],[-20.24,3.18],[-56.71,3.18],[-55.89,5.03],[-54.64,6.70],[-20.24,-3.30],[-20.24,-6.82],[-54.60,-6.82],[-56.16,-4.59],[-56.55,-3.30],[-20.24,-13.30],[-20.24,-20.30],[-13.24,-20.30],[-13.24,-23.06],[-13.10,-24.00],[-12.29,-25.35],[-11.24,-26.05],[-10.32,-26.28],[-9.06,-26.16],[-8.20,-25.75],[-7.50,-25.11],[-6.82,-23.69],[-6.76,-20.30],[-3.24,-20.30],[-3.22,-23.37],[-2.99,-24.30],[-2.55,-25.06],[-3.10,-26.12],[-3.24,-27.06],[-3.24,-44.90],[-4.29,-45.36],[-6.89,-47.17],[-8.70,-49.77],[-9.09,-50.58],[-11.35,-50.16],[-14.40,-48.53],[-17.00,-45.87],[-18.05,-45.26],[-19.25,-45.09],[-22.17,-45.72],[-24.17,-45.79],[-26.15,-45.46],[-28.03,-44.75],[-29.74,-43.69],[-31.20,-42.32],[-32.37,-40.69],[-33.48,-38.28],[-34.30,-37.34],[-35.42,-36.78],[-39.27,-36.09],[-42.27,-34.49],[-44.16,-32.60],[-45.19,-30.94],[-45.81,-29.30],[-37.62,-29.30],[-32.39,-36.25],[-31.65,-36.84],[-30.77,-37.20],[-29.51,-37.26],[-28.06,-36.65],[-27.06,-35.43],[-26.76,-33.88],[-26.96,-32.95],[-27.41,-32.11],[-33.41,-24.11],[-34.12,-23.42],[-35.01,-22.97],[-36.00,-22.82],[-46.00,-22.82],[-46.94,-22.96],[-48.05,-23.55],[-51.42,-21.27],[-53.39,-18.51],[-54.06,-16.73],[-54.39,-14.75],[-54.34,-13.30],[2.55,-25.06],[3.22,-23.37],[3.24,-20.30],[6.76,-20.30],[6.78,-23.37],[7.14,-24.58],[7.71,-25.35],[8.47,-25.91],[10.00,-26.30],[11.53,-25.91],[12.29,-25.35],[12.86,-24.58],[13.22,-23.37],[13.24,-20.30],[20.24,-20.30],[20.24,-13.30],[54.23,-13.30],[54.40,-14.22],[54.21,-16.08],[53.63,-18.00],[52.68,-19.77],[51.51,-21.21],[48.05,-23.55],[46.94,-22.96],[46.00,-22.82],[36.00,-22.82],[35.34,-22.89],[34.40,-23.24],[33.41,-24.11],[27.41,-32.11],[26.96,-32.95],[26.76,-33.88],[26.94,-35.13],[27.81,-36.45],[29.20,-37.20],[30.77,-37.20],[31.65,-36.84],[32.39,-36.25],[37.62,-29.30],[45.78,-29.30],[45.50,-30.23],[43.63,-33.24],[42.24,-34.54],[40.54,-35.60],[38.69,-36.29],[35.51,-36.75],[34.34,-37.31],[33.48,-38.28],[32.37,-40.69],[31.20,-42.32],[29.74,-43.69],[28.03,-44.75],[26.15,-45.46],[24.17,-45.79],[22.17,-45.72],[19.23,-45.09],[17.99,-45.28],[16.92,-45.93],[14.89,-48.15],[13.28,-49.31],[11.45,-50.13],[9.55,-50.58],[9.09,-50.58],[7.29,-47.66],[6.65,-46.96],[4.29,-45.36],[3.24,-44.90],[3.24,-27.06],[3.1
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

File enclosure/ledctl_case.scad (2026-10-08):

// ESP32-C3 LED Strip Controller - 3D printable enclosure (rev A)
// Coordinates: X = board_x - 100, Y = 138 - board_y (KiCad board coords),
// so the PCB occupies X 0..64, Y 0..38; USB-C faces -Y, terminals face -X.
//
// Render:  openscad -D 'part="base"' -o base.stl ledctl_case.scad
//          openscad -D 'part="lid"'  -o lid.stl  ledctl_case.scad
// part = "base" | "lid" | "assembly"

part = "assembly";

include <bilginier_logo.scad>

/* [Fit] */
clr        = 0.5;    // PCB to wall clearance
wall       = 2.0;
floor_t    = 2.0;
lid_t      = 2.0;
corner_r   = 3.0;

/* [PCB] */
pcb_w      = 64;
pcb_h      = 38;
pcb_t      = 1.6;
standoff_h = 5.0;    // floor top -> PCB bottom (room for THT pins + keyhole screw heads)
comp_h     = 11.5;   // PCB top -> lid underside (terminal blocks ~10 mm, pin header 8.5 mm)
antenna_x  = 70.0;   // ESP32-C3-WROOM-02 overhangs the right PCB edge

/* [Fasteners] */
// M3 screws go lid -> lid post -> PCB hole -> base standoff. M3x20 recommended.
standoff_d   = 6.5;
pilot_d      = 2.6;  // M3 self-tapping into plastic (use 4.0 for M3 heat-set inserts)
post_d       = 5.5;
screw_clear  = 3.4;

/* [Wall mount] */
keyhole_head = 8.5;  // screw head pass-through
keyhole_slot = 4.2;  // screw shank
keyhole_len  = 8.0;

$fn = 48;

// ---------------------------------------------------------------- data
holes = [[59, 35.0], [59, 3.5], [4, 3.4], [14.5, 21.2]];   // H1..H4
term_pins  = [[5, 33.5], [5, 28.4], [5, 16.0], [5, 10.9]]; // J1+, J1-, J2+, J2-
term_spans = [[25.88, 36.04], [8.38, 18.54]];               // J1, J2 (Y range)
usb_c      = [30, 0];                                       // J3 mouth center
buttons    = [[15, 4.5, "RST"], [42.5, 4.5, "BTN"]];        // SW1, SW2
status_led = [49.5, 3.4];                                   // D4
keyholes   = [[25, 14], [45, 14]];                          // slot points +Y (= up on the wall)

// derived
in_x0 = -clr;            in_x1 = antenna_x + 1.0;
in_y0 = -clr;            in_y1 = pcb_h + clr;
out_x0 = in_x0 - wall;   out_x1 = in_x1 + wall;
out_y0 = in_y0 - wall;   out_y1 = in_y1 + wall;
pcb_z  = floor_t + standoff_h;          // PCB bottom
top_z  = pcb_z + pcb_t;                 // PCB top
base_h = top_z + comp_h;                // base wall height = lid underside

module rrect(x0, y0, x1, y1, h, r) {
  translate([x0 + r, y0 + r, 0])
    linear_extrude(h) offset(r) square([x1 - x0 - 2 * r, y1 - y0 - 2 * r]);
}

module slot2d(l, w) { hull() { circle(d = w); translate([l, 0]) circle(d = w); } }

// ---------------------------------------------------------------- base
module base() {
  difference() {
    union() {
      difference() {
        rrect(out_x0, out_y0, out_x1, out_y1, base_h, corner_r);
        translate([0, 0, floor_t]) rrect(in_x0, in_y0, in_x1, in_y1, base_h, 1);
      }
      for (h = holes) translate([h[0], h[1], 0]) cylinder(d = standoff_d, h = pcb_z);
    }
    // standoff pilot holes
    for (h = holes) translate([h[0], h[1], floor_t - 1.5]) cylinder(d = pilot_d, h = 50);
    // terminal block wire openings (left wall)
    for (s = term_spans)
      translate([out_x0 - 1, s[0] - 0.5, top_z - 0.2]) cube([wall + 2, s[1] - s[0] + 1, 8.2]);
    // USB-C opening (front wall), sized for typical cable overmolds
    translate([usb_c[0], out_y0 - 1, top_z + 1.6]) rotate([-90, 0, 0])
      linear_extrude(wall + 2) offset(2.5) square([11 - 5, 6.5 - 5], center = true);
    // wall keyholes
    for (k = keyholes) translate([k[0], k[1], -1]) {
      cylinder(d = keyhole_head, h = floor_t + 2);
      linear_extrude(floor_t + 2) rotate(90) slot2d(keyhole_len, keyhole_slot);
    }
    // bottom label
    translate([(out_x0 + out_x1) / 2, out_y1 - 8, -0.01]) mirror([1, 0, 0])
      linear_extrude(0.5) text("LED CTRL rev A", size = 4, halign = "center", font = "Liberation Sans:style=Bold");
  }
}

// ---------------------------------------------------------------- lid
peg_gap  = 0.4;   // peg tip to tact switch actuator
sw_h     = 1.5;   // TS-1187A actuator height
module lid() {
  tongue_w = 6; tongue_l = 13; cut = 0.8;
  difference() {
    union() {
      rrect(out_x0, out_y0, out_x1, out_y1, lid_t, corner_r);
      // screw posts that clamp the PCB onto the standoffs
      for (h = holes) translate([h[0], h[1], -comp_h]) cylinder(d = post_d, h = comp_h);
      // button pegs hanging from the flexure tongues
      for (b = buttons) translate([b[0], b[1], -(comp_h - sw_h - peg_gap)])
        cylinder(d = 3, h = comp_h - sw_h - peg_gap);
      // status LED light tube
      translate([status_led[0], status_led[1], -(comp_h - 1)]) cylinder(d = 3.6, h = comp_h - 1);
      // stiffening rim that keys into the base opening (skips the terminal side)
      difference() {
        translate([0, 0, -2]) rrect(in_x0 + 0.3, in_y0 + 0.3, in_x1 - 0.3, in_y1 - 0.3, 2, 1);
        translate([0, 0, -3]) rrect(in_x0 + 1.5, in_y0 + 1.5, in_x1 - 1.5, in_y1 - 1.5, 4, 1);
        translate([in_x0 - 1, in_y0 - 1, -3]) cube([12, in_y1 - in_y0 + 2, 4]);   // terminal blocks
        translate([usb_c[0] - 8, in_y0 - 1, -3]) cube([16, 3, 4]);                // USB-C
      }
    }
    // screw holes + head counterbore
    for (h = holes) translate([h[0], h[1], -comp_h - 1]) cylinder(d = screw_clear, h = comp_h + lid_t + 2);
    // terminal screwdriver access
    for (p = term_pins) translate([p[0] - 1, p[1], -1]) linear_extrude(lid_t + 2) slot2d(2, 4.2);
    // flexure tongues: U-shaped cut around each button pad, hinge toward +Y
    for (b = buttons) translate([b[0], b[1], -1]) linear_extrude(lid_t + 2) difference() {
      translate([-tongue_w / 2 - cut, -tongue_w / 2 - cut]) square([tongue_w + 2 * cut, tongue_l + cut]);
      translate([-tongue_w / 2, -tongue_w / 2]) square([tongue_w, tongue_l + 1]);
    }
    // light tube bore
    translate([status_led[0], status_led[1], -comp_h]) cylinder(d = 2.2, h = comp_h + lid_t + 1);
    // engraved labels
    engrave = 0.6;
    translate([0, 0, lid_t - engrave]) linear_extrude(engrave + 1) {
      for (p = term_pins) translate([8.6, p[1]])
        text(p[1] == 33.5 || p[1] == 16.0 ? "+" : "-", size = 3, valign = "center", font = "Liberation Sans:style=Bold");
      translate([-1, 37.8]) text("12-24V IN", size = 2.6, font = "Liberation Sans:style=Bold");
      translate([-1, 20.5]) text("LED", size = 2.6, font = "Liberation Sans:style=Bold");
      for (b = buttons) translate([b[0] + 4.3, b[1] + tongue_l - 5]) text(b[2], size = 2.6, font = "Liberation Sans:style=Bold");
      translate([status_led[0], status_led[1] + 2.6]) text("WiFi", size = 2.2, halign = "center", font = "Liberation Sans:style=Bold");
      translate([40, 30]) bilginier_logo(12);
      translate([40, 19.6]) text("LED Controller", size = 3.6, halign = "center", font = "Liberation Sans:style=Bold");
      translate([40, 15.9]) text("BILGINIER", size = 2.3, spacing = 1.35, halign = "center", font = "Liberation Sans:style=Bold");
    }
  }
}

// ---------------------------------------------------------------- output
module pcb_dummy() {
  color("darkgreen") translate([0, 0, pcb_z]) cube([pcb_w, pcb_h, pcb_t]);
  color("silver") translate([49.8, 9, top_z]) cube([20.1, 18, 3.2]);           // ESP module
  color("green") for (s = term_spans) translate([0.4, s[0], top_z]) cube([9.8, s[1] - s[0], 10]);
  color("gray") translate([25.4, -0.4, top_z]) cube([9.2, 7.4, 3.2]);          // USB-C
}

if (part == "base") base();
else if (part == "lid") translate([0, 0, lid_t]) mirror([0, 0, 1]) lid();   // print face-down
else {
  color("#e8e6e0") base();
  pcb_dummy();
  color("#f0a040", 0.85) translate([0, 0, base_h + 8]) lid();
}

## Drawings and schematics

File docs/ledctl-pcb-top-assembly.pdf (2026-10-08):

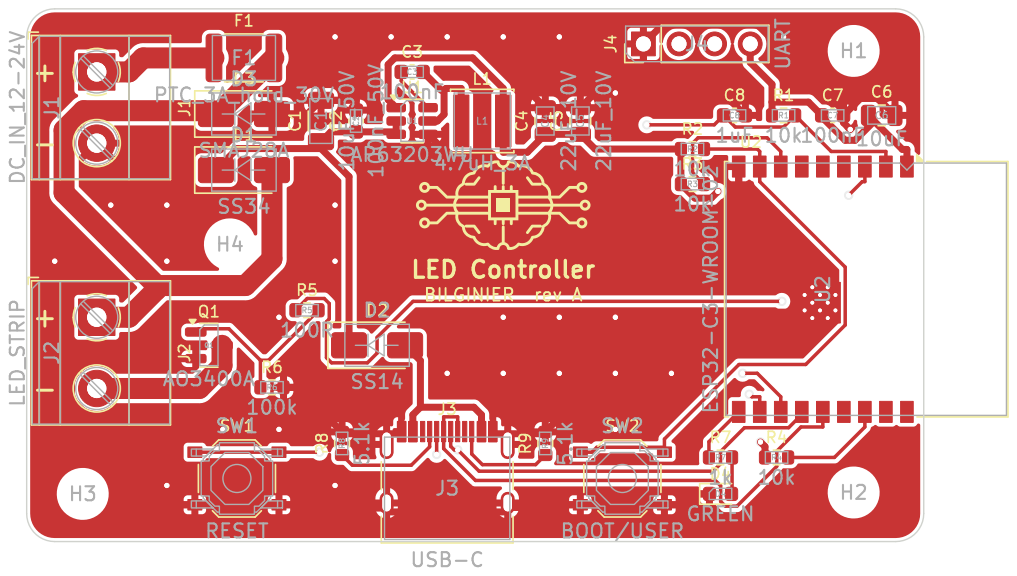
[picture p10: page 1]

C7 BOOT/USER

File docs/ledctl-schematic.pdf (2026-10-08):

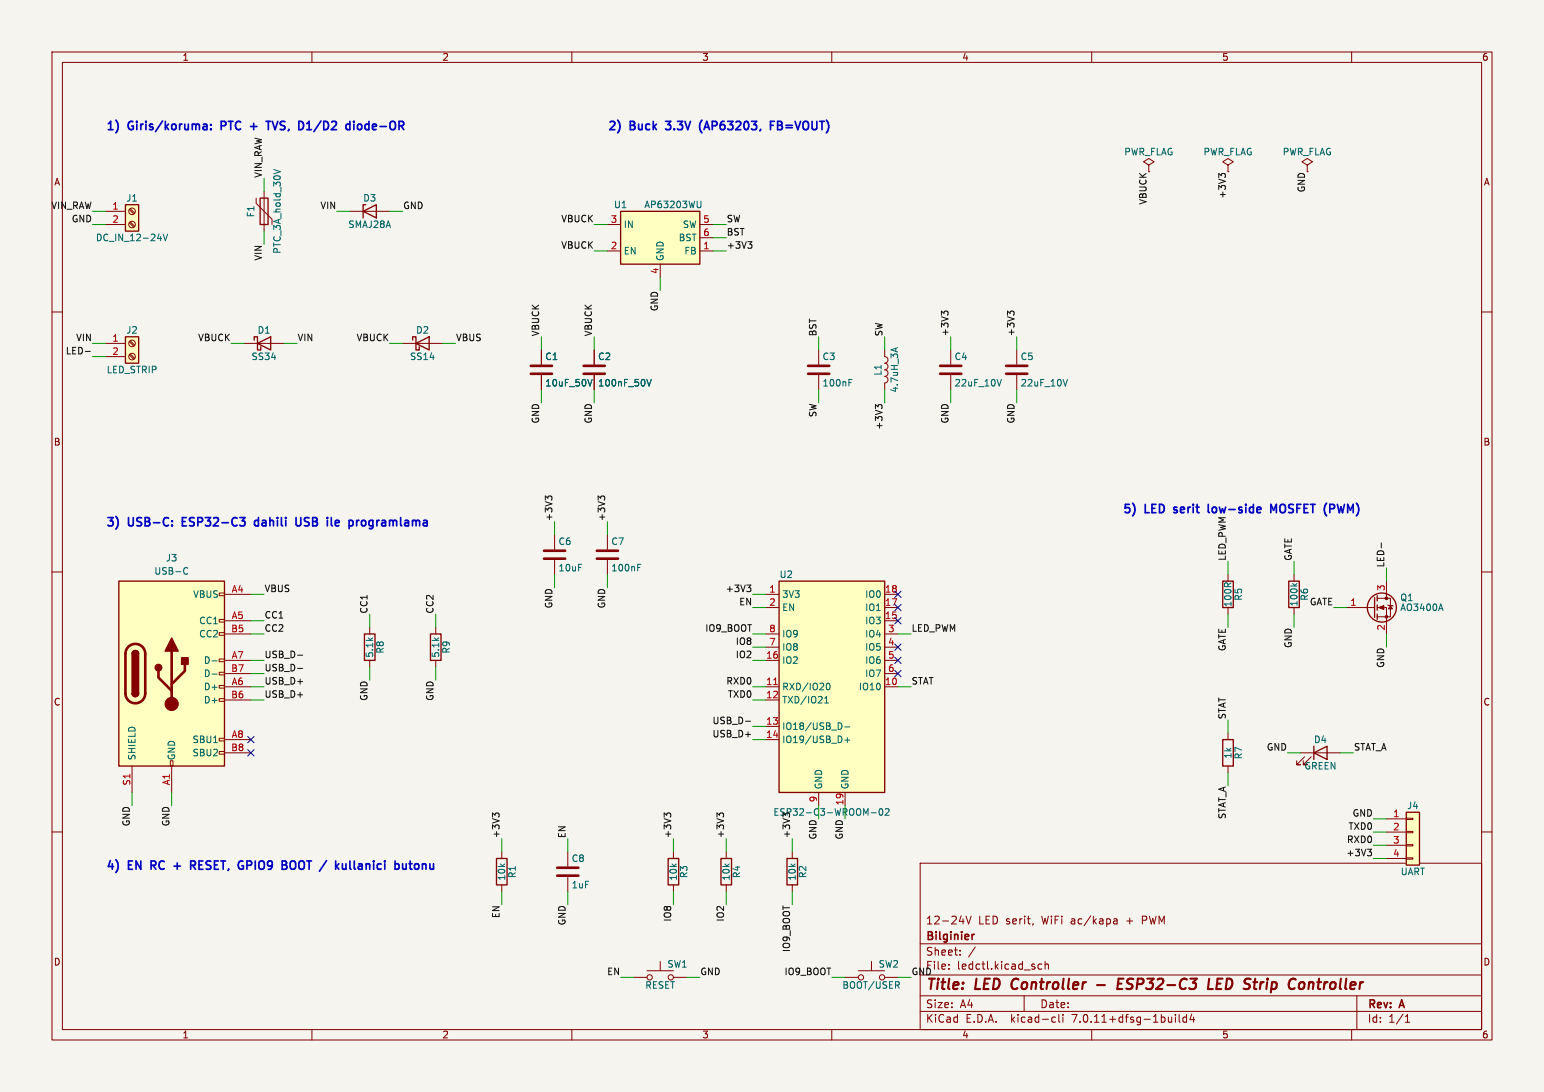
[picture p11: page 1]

4) EN RC + RESET, GPIO9 BOOT / kullanici butonu

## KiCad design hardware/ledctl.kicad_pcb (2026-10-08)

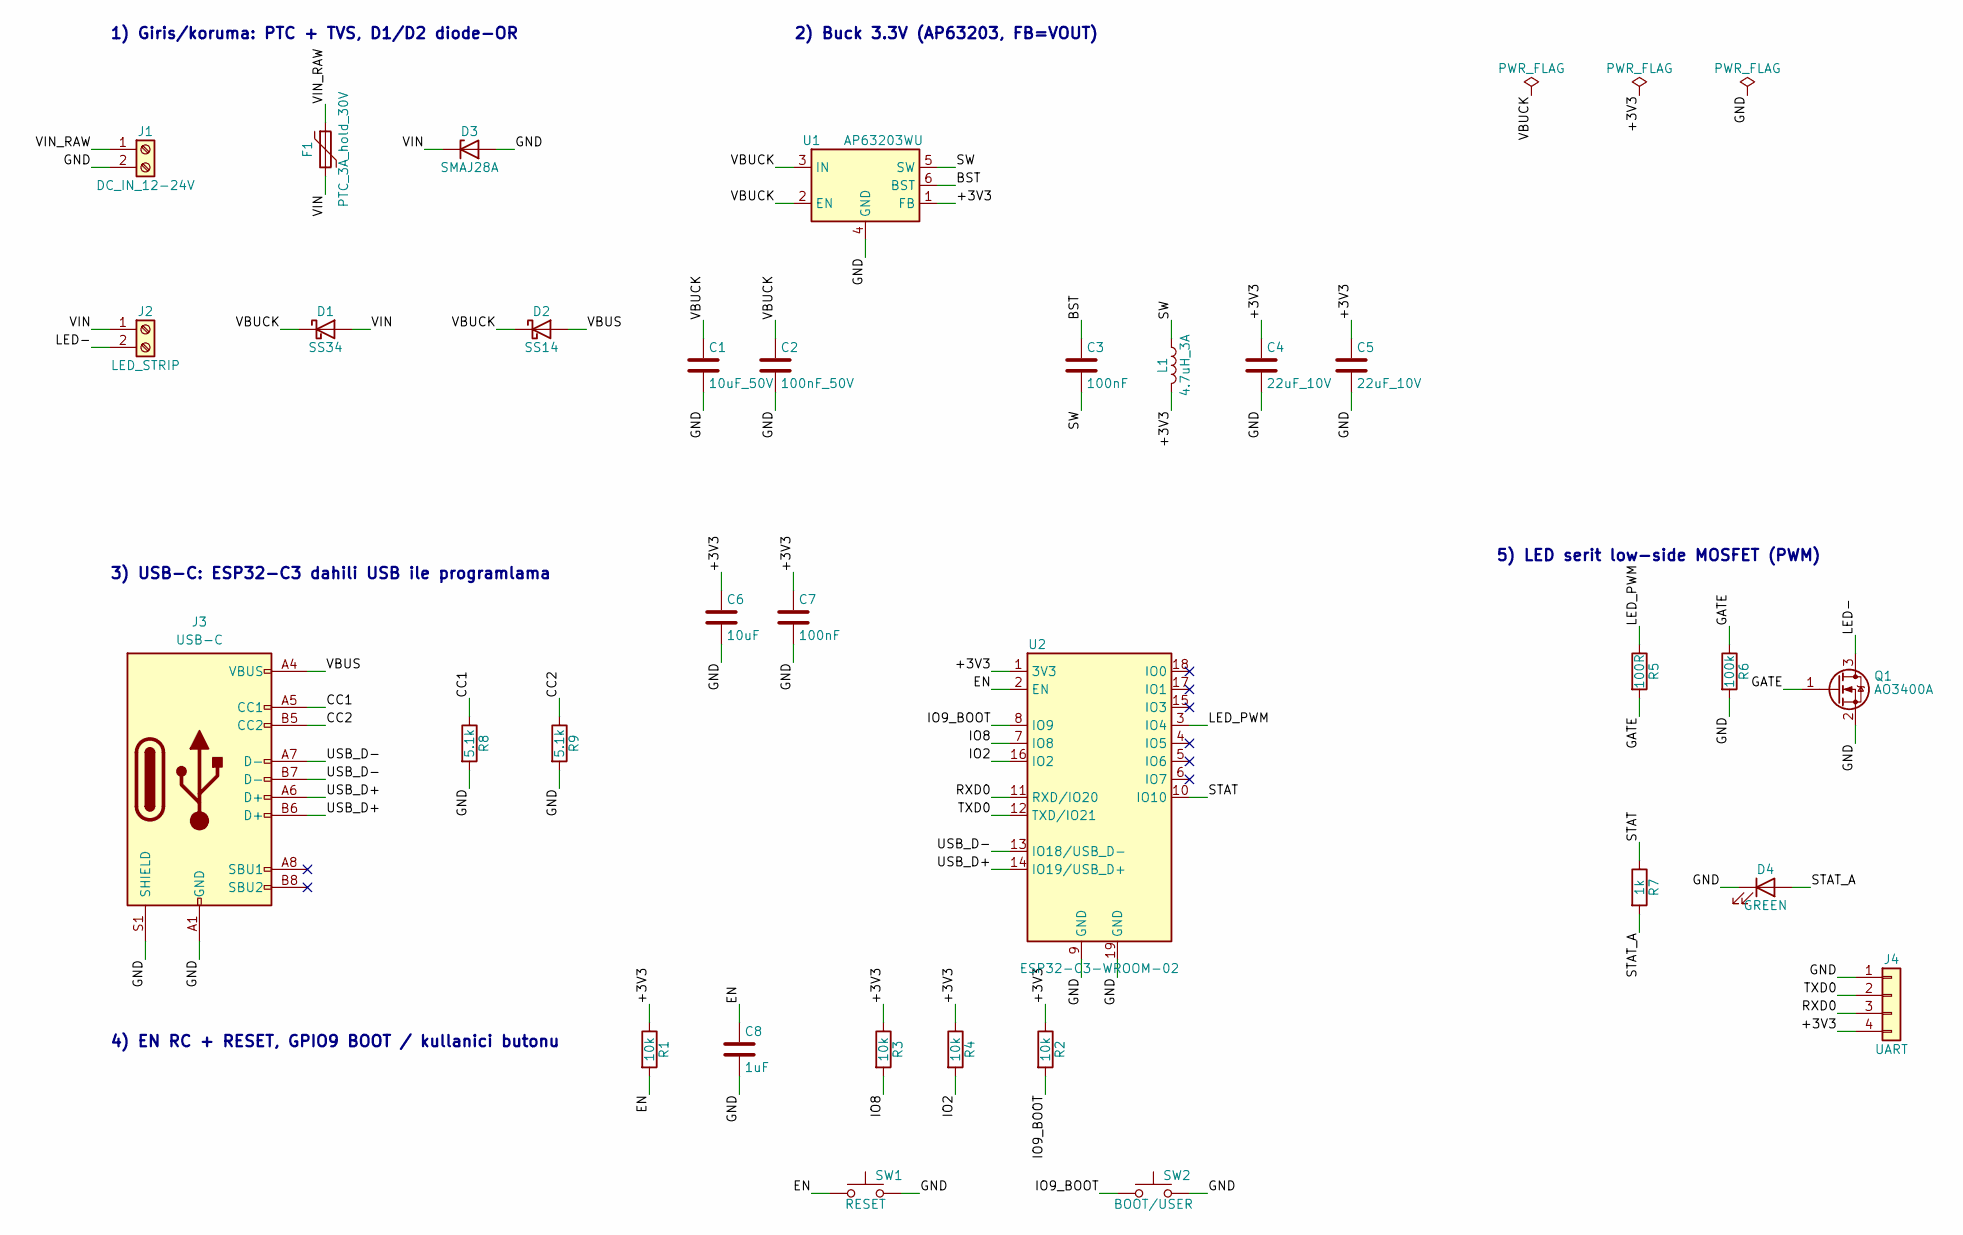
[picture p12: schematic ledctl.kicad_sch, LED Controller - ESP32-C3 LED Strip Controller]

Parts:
C1: 10uF_50V; C_1206_3216Metric
C2: 100nF_50V; C_0603_1608Metric
C3, C7: 100nF; C_0603_1608Metric
C4, C5: 22uF_10V; C_0805_2012Metric
C6: 10uF; C_0805_2012Metric
C8: 1uF; C_0603_1608Metric
D1: SS34; D_SMA
D2: SS14; D_SMA
D3: SMAJ28A; D_SMA
D4: GREEN; LED_0603_1608Metric
F1: PTC_3A_hold_30V; Fuse_1812_4532Metric
J1: DC_IN_12-24V; TerminalBlock_Phoenix_MKDS-1,5-2-5.08_1x02_P5.08mm_Horizont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
J2: LED_STRIP; TerminalBlock_Phoenix_MKDS-1,5-2-5.08_1x02_P5.08mm_Horizont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
J3: USB-C; USB_C_Receptacle_HRO_TYPE-C-31-M-12
J4: UART; PinHeader_1x04_P2.54mm_Vertical
L1: 4.7uH_3A; L_Changjiang_FNR4030S
Q1: AO3400A; SOT-23
R1, R2, R3, R4: 10k; R_0603_1608Metric
R5: 100R; R_0603_1608Metric
R6: 100k; R_0603_1608Metric
R7: 1k; R_0603_1608Metric
R8, R9: 5.1k; R_0603_1608Metric
SW1: RESET; SW_Push_1P1T_XKB_TS-1187A
SW2: BOOT/USER; SW_Push_1P1T_XKB_TS-1187A
U1: AP63203WU; TSOT-23-6
U2: ESP32-C3-WROOM-02

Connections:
+3V3: C4.1, C5.1, C6.1, C7.1, J4.4, L1.2, R1.1, R2.1, R3.1, R4.1, U1.1 (FB), U2.1 (3V3)
BST: C3.1, U1.6 (BST)
CC1: J3.A5 (CC1), R8.1
CC2: J3.B5 (CC2), R9.1
EN: C8.1, R1.2, SW1.1, U2.2 (EN)
GATE: Q1.1 (G), R5.2, R6.1
GND: C1.2, C2.2, C4.2, C5.2, C6.2, C7.2, C8.2, D3.2 (A), D4.1 (K), J1.2, J3.A1 (GND), J3.A12 (GND), J3.B1 (GND), J3.B12 (GND), J3.S1 (SHIELD), J4.1, Q1.2 (S), R6.2, R8.2, R9.2, SW1.2, SW2.2, U1.4 (GND), U2.9 (GND), U2.19 (GND)
IO2: R4.2, U2.16 (IO2)
IO8: R3.2, U2.7 (IO8)
IO9_BOOT: R2.2, SW2.1, U2.8 (IO9)
LED-: J2.2, Q1.3 (D)
LED_PWM: R5.1, U2.3 (IO4)
RXD0: J4.3, U2.11 (RXD/IO20)
STAT: R7.1, U2.10 (IO10)
STAT_A: D4.2 (A), R7.2
SW: C3.2, L1.1, U1.5 (SW)
TXD0: J4.2, U2.12 (TXD/IO21)
USB_D+: J3.A6 (D+), J3.B6 (D+), U2.14 (IO19/USB_D+)
USB_D-: J3.A7 (D-), J3.B7 (D-), U2.13 (IO18/USB_D-)
VBUCK: C1.1, C2.1, D1.1 (K), D2.1 (K), U1.2 (EN), U1.3 (IN)
VBUS: D2.2 (A), J3.A4 (VBUS), J3.A9 (VBUS), J3.B4 (VBUS), J3.B9 (VBUS)
VIN: D1.2 (A), D3.1 (K), F1.2, J2.1
VIN_RAW: F1.1, J1.1

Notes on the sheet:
1) Giris/koruma: PTC + TVS, D1/D2 diode-OR
2) Buck 3.3V (AP63203, FB=VOUT)
3) USB-C: ESP32-C3 dahili USB ile programlama
4) EN RC + RESET, GPIO9 BOOT / kullanici butonu
5) LED serit low-side MOSFET (PWM)

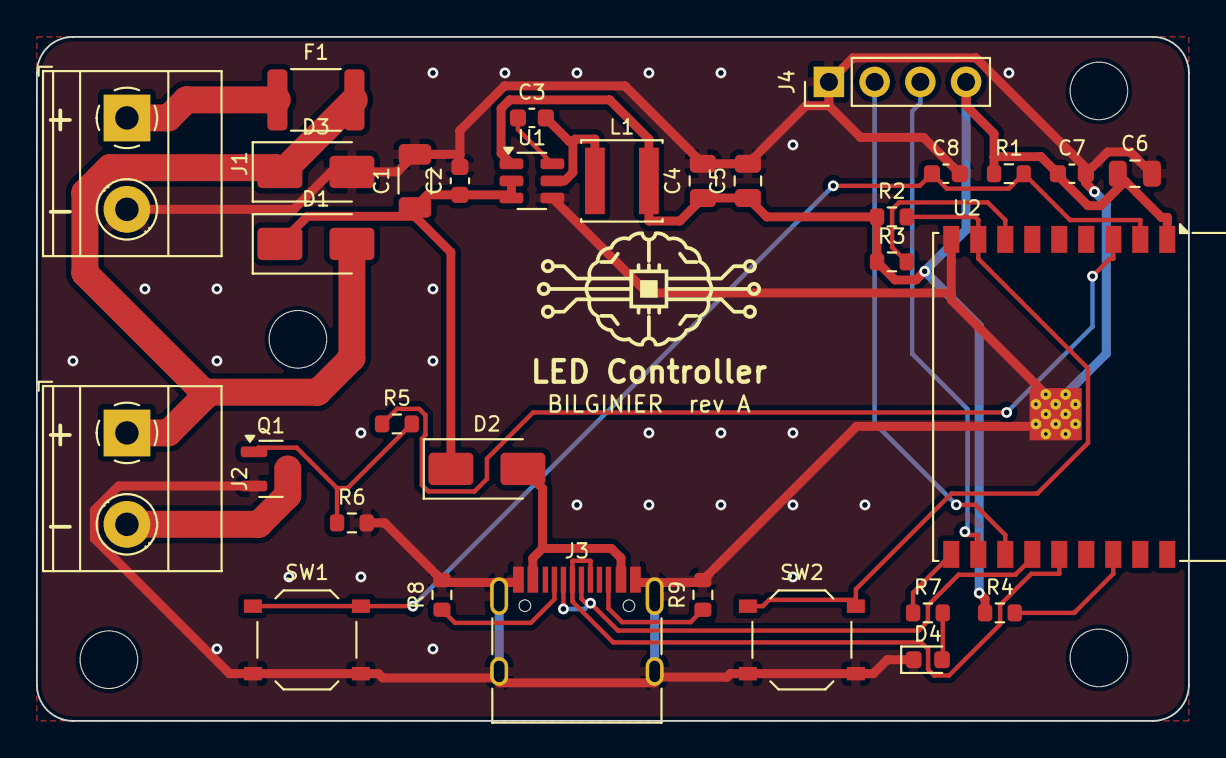
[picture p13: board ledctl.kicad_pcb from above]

Board: 2 copper layers, 64.0 x 38.0 mm, 36 parts (0 on the bottom side), 23 nets.

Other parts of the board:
H1, H2, H3, H4: MountingHole_3.2mm_M3

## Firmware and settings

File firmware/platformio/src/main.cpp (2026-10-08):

// ESP32-C3 LED Strip Controller - standalone firmware
// Features: WiFi captive-portal setup, web UI, REST API, physical button,
//           smooth PWM dimming, state persistence, mDNS, ArduinoOTA.
#include <Arduino.h>
#include <WiFi.h>
#include <WebServer.h>
#include <ESPmDNS.h>
#include <ArduinoOTA.h>
#include <Preferences.h>
#include <WiFiManager.h>
#include <ArduinoJson.h>
#include "config.h"
#include "web_ui.h"

WebServer server(80);
Preferences prefs;

// ------------------------------------------------------------------ state
struct State {
  bool on = false;
  uint8_t brightness = 100;  // percent, 1..100
} state;

static float currentDuty = 0;  // 0..1, what is on the pin now
static float startDuty = 0, targetDuty = 0;
static uint32_t fadeStart = 0;
static bool dirty = false;
static uint32_t dirtySince = 0;

// perceptual (gamma 2.2) brightness -> duty
static float pctToDuty(uint8_t pct) { return powf(pct / 100.0f, 2.2f); }

static void writeDuty(float d) {
  const uint32_t maxv = (1u << PWM_BITS) - 1;
  ledcWrite(PWM_CHANNEL, (uint32_t)lroundf(constrain(d, 0.0f, 1.0f) * maxv));
}

static void applyState() {
  startDuty = currentDuty;
  targetDuty = state.on ? pctToDuty(state.brightness) : 0.0f;
  fadeStart = millis();
  dirty = true;
  dirtySince = millis();
}

static void fadeLoop() {
  if (currentDuty == targetDuty) return;
  float t = (millis() - fadeStart) / (float)FADE_MS;
  currentDuty = t >= 1.0f ? targetDuty : startDuty + (targetDuty - startDuty) * t;
  writeDuty(currentDuty);
}

static void saveLoop() {
  if (dirty && millis() - dirtySince > SAVE_DELAY_MS) {
    prefs.putBool("on", state.on);
    prefs.putUChar("bri", state.brightness);
    dirty = false;
  }
}

static void setOn(bool on) { state.on = on; applyState(); }
static void toggle() { setOn(!state.on); }
static void setBrightness(int pct) {
  state.brightness = (uint8_t)constrain(pct, 1, 100);
  applyState();
}

// ------------------------------------------------------------------ button
// short press: toggle | hold: cycle brightness 100->75->50->25->10 | 8 s: WiFi reset
static void buttonLoop() {
  static bool lastRaw = true, stable = true;
  static uint32_t changedAt = 0, pressedAt = 0;
  static bool longFired = false;
  bool raw = digitalRead(PIN_BUTTON);  // HIGH = released
  uint32_t now = millis();
  if (raw != lastRaw) { lastRaw = raw; changedAt = now; }
  if (now - changedAt < BUTTON_DEBOUNCE_MS || raw == stable) {
    if (!stable && !longFired && now - pressedAt > BUTTON_LONG_MS) {
      static const uint8_t steps[] = {100, 75, 50, 25, 10};
      size_t i = 0;
      while (i < sizeof(steps) && steps[i] > state.brightness) i++;
      state.brightness = steps[(i + 1) % sizeof(steps)];
      state.on = true;
      applyState();
      longFired = true;
    }
    if (!stable && now - pressedAt > BUTTON_RESET_MS) {
      Serial.println("[btn] WiFi reset");
      for (int i = 0; i < 10; i++) { digitalWrite(PIN_STATUS, i & 1); delay(100); }
      WiFiManager wm;
      wm.resetSettings();
      ESP.restart();
    }
    return;
  }
  stable = raw;
  if (!stable) { pressedAt = now; longFired = false; }
  else if (!longFired) toggle();  // released before long-press
}

// ------------------------------------------------------------------ status LED
// solid = connected, slow blink = connecting, fast blink = setup portal
enum class Net { Connecting, Portal, Online } net = Net::Connecting;
static void statusLoop() {
  uint32_t ms = millis();
  bool v = net == Net::Online ? true : net == Net::Portal ? (ms / 150) & 1 : (ms / 600) & 1;
  digitalWrite(PIN_STATUS, v);
}

// ------------------------------------------------------------------ web
static void sendState() {
  JsonDocument doc;
  doc["on"] = state.on;
  doc["brightness"] = state.brightness;
  doc["rssi"] = WiFi.RSSI();
  doc["ip"] = WiFi.localIP().toString();
  doc["uptime_s"] = millis() / 1000;
  String out;
  serializeJson(doc, out);
  server.send(200, "application/json", out);
}

static void handlePost() {
  JsonDocument doc;
  if (deserializeJson(doc, server.arg("plain"))) {
    server.send(400, "application/json", "{\"error\":\"invalid json\"}");
    return;
  }
  if (doc["brightness"].is<int>()) state.brightness = constrain((int)doc["brightness"], 1, 100);
  if (doc["on"].is<bool>()) state.on = doc["on"];
  if (doc["toggle"] | false) state.on = !state.on;
  applyState();
  sendState();
}

static void setupWeb() {
  server.on("/", HTTP_GET, [] { server.send_P(200, "text/html", INDEX_HTML); });
  server.on("/api/state", HTTP_GET, sendState);
  server.on("/api/state", HTTP_POST, handlePost);
  server.on("/api/toggle", HTTP_POST, [] { toggle(); sendState(); });
  server.onNotFound([] { server.send(404, "text/plain", "not found"); });
  server.begin();
}

// ------------------------------------------------------------------ setup/loop
void setup() {
  // LED off as early as possible (gate also has a 100k pull-down)
  ledcSetup(PWM_CHANNEL, PWM_FREQ_HZ, PWM_BITS);
  ledcAttachPin(PIN_LED_PWM, PWM_CHANNEL);
  writeDuty(0);
  pinMode(PIN_BUTTON, INPUT_PULLUP);
  pinMode(PIN_STATUS, OUTPUT);

  Serial.begin(115200);
  prefs.begin("ledctl", false);
  state.on = prefs.getBool("on", false);
  state.brightness = prefs.getUChar("bri", 100);
  applyState();
  dirty = false;

  WiFi.setHostname(HOSTNAME);
  WiFiManager wm;
  wm.setConfigPortalBlocking(false);
  wm.setAPCallback([](WiFiManager*) { net = Net::Portal; });
  if (!wm.autoConnect(AP_NAME)) {
    // portal running: keep LED + button working until configured
    while (WiFi.status() != WL_CONNECTED) {
      wm.process();
      buttonLoop(); fadeLoop(); saveLoop(); statusLoop();
      delay(2);
    }
  }
  net = Net::Online;
  Serial.printf("[wifi] %s  http://%s.local\n", WiFi.localIP().toString().c_str(), HOSTNAME);

  MDNS.begin(HOSTNAME);
  MDNS.addService("http", "tcp", 80);
  ArduinoOTA.setHostname(HOSTNAME);
  ArduinoOTA.begin();
  setupWeb();
}

void loop() {
  server.handleClient();
  ArduinoOTA.handle();
  buttonLoop();
  fadeLoop();
  saveLoop();
  net = WiFi.status() == WL_CONNECTED ? Net::Online : Net::Connecting;
  statusLoop();
  delay(1);
}

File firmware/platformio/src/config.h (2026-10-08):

#pragma once

// ---- Pin map (hardware rev A, see hardware/ledctl.kicad_sch) ----
constexpr int PIN_LED_PWM = 4;   // IO4 -> R5 -> Q1 (AO3400A) gate, low-side switch
constexpr int PIN_BUTTON  = 9;   // IO9 BOOT button (SW2), active low, R2 pull-up
constexpr int PIN_STATUS  = 10;  // IO10 -> R7 -> D4 green status LED, active high

// ---- PWM ----
constexpr uint32_t PWM_FREQ_HZ  = 20000;  // above audible range, no coil whine
constexpr uint8_t  PWM_BITS     = 10;     // 0..1023
constexpr uint8_t  PWM_CHANNEL  = 0;

// ---- Behaviour ----
constexpr uint32_t FADE_MS            = 300;    // on/off/brightness transition
constexpr uint32_t BUTTON_DEBOUNCE_MS = 30;
constexpr uint32_t BUTTON_LONG_MS     = 800;    // hold: dim cycle
constexpr uint32_t BUTTON_RESET_MS    = 8000;   // hold 8 s: forget WiFi & reboot
constexpr uint32_t SAVE_DELAY_MS      = 2000;   // debounce NVS writes

constexpr const char* HOSTNAME = "led-ctrl";
constexpr const char* AP_NAME  = "LedCtrl-Setup";   // captive portal SSID

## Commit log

2026-10-08 Initial commit: ESP32-C3 LED strip controller rev A
    - KiCad schematic + 2-layer PCB (64x38 mm), Gerbers, drill, pos, BOM
    - ESPHome config and standalone PlatformIO firmware (web UI, REST, button, PWM)
    - Parametric OpenSCAD enclosure with printable STLs (wall keyholes, flat base)
    Claude-Session: https://claude.ai/code/session_01N8odZzQsCCUC5sRgiuL7xi
    [BOM.csv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]
2026-10-08 docs: add readable BOM (hardware/BOM.md) and BOM summary in README
    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
2026-10-08 Add Bilginier branding and LCSC part numbers
    - Bilginier circuit-brain logo (docs/logo/logo.py) as single source for
    SVG/banner, PCB silkscreen (add_branding.py) and engraved enclosure lid
    - README banner with light/dark variants, schematic title block
    - BOM.csv/BOM.md: verified LCSC numbers, JLCPCB BOM + CPL exports
    - F1: flag that no 1812 PTC covers 3 A at 24 V (decision pending)
    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
    [BOM.csv, bilginier_logo.scad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]
